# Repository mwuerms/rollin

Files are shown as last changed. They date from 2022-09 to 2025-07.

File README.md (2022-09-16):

# rollin
a self balancing robot, "rolling around"

## Test 1

quick prototyp for using MPU9250 to get acc x, y values and gyro z values (change rate in deg/s !) to calculate present angle:

 +   0° is upright
 + -90° fall over foreward
 +  90° fall over backwards

## Better Serial Plotter

A very nice serial plotter tool (win, mac, linux), using space ' ' or tabs '\t' as value separator.

https://github.com/nathandunk/BetterSerialPlotter#example-arduino-code

Thank you nathandunk (https://github.com/nathandunk)

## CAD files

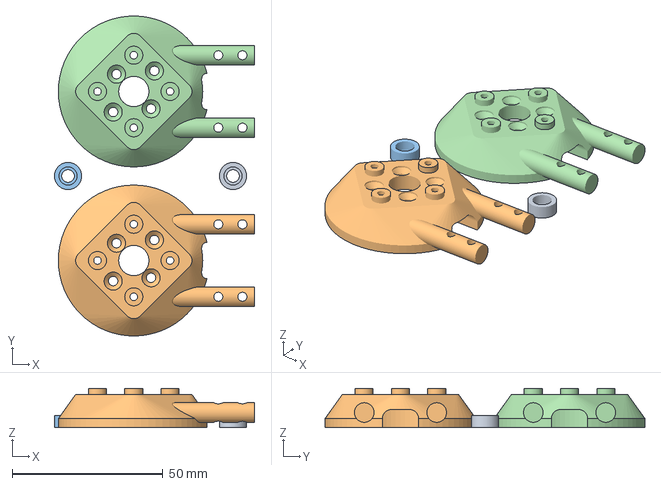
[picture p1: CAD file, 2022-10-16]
openscad/r02/r02_magnet_holder_v1.0.3mf
66.3 x 106.0 x 13.0 mm
r02_magnet_holder_v1.0.stl x 2
r02_motor_holder_v1.0.stl x 2

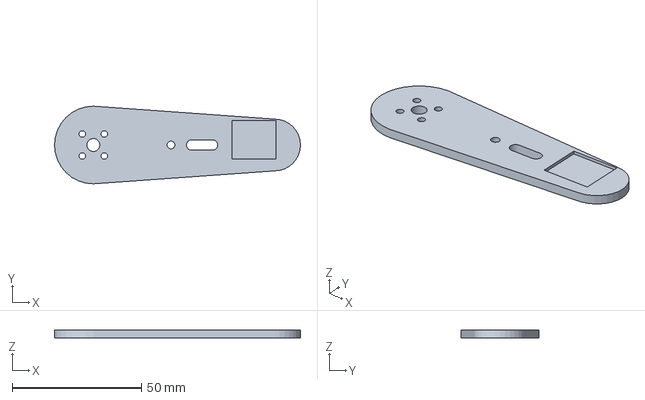
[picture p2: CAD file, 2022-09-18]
openscad/teststand/motor_holderv1.0.3mf
95.0 x 30.0 x 3.00 mm

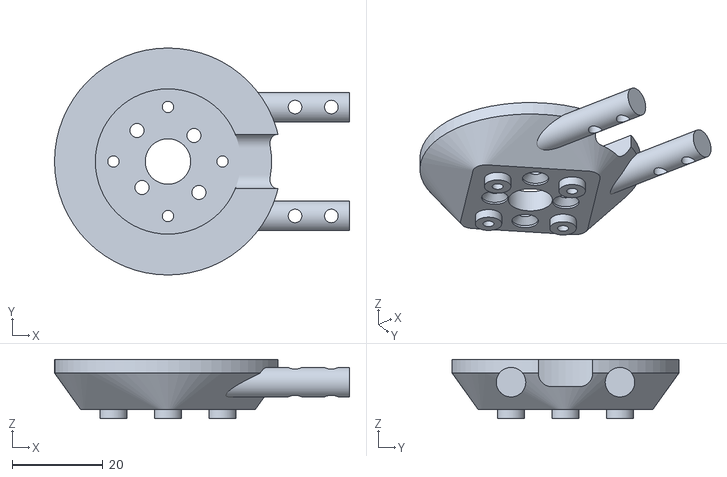
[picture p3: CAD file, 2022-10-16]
openscad/r02/r02_motor_holder_v1.0.stl
65.0 x 50.0 x 13.0

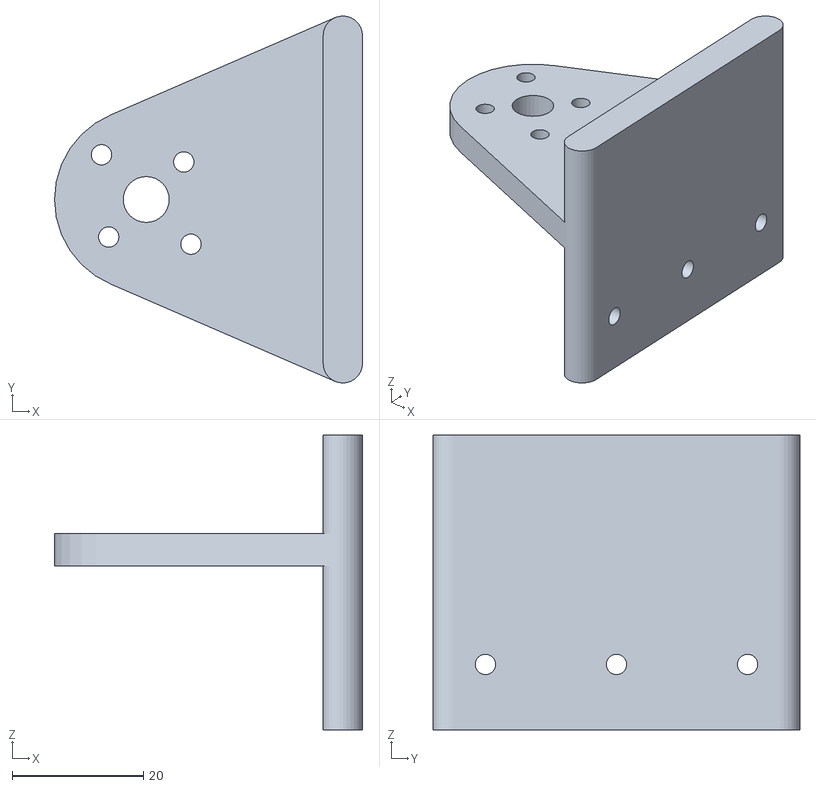
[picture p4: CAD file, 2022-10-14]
openscad/r02/r02_test_stand_v1.0.stl
47.0 x 56.0 x 45.0

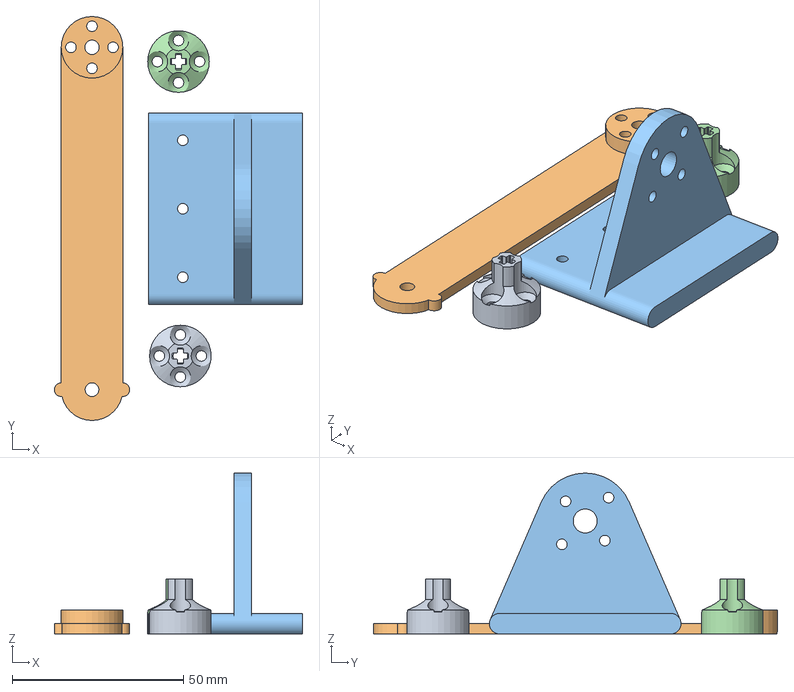
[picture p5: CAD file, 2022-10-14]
openscad/r02/r02_lego_wheel_holder_v1.1.3mf
72.5 x 118.0 x 47.0 mm
r02_lego_wheel_holder_v1.1.stl x 2
r02_test_arm_v1.0.stl
r02_test_stand_v1.0.stl

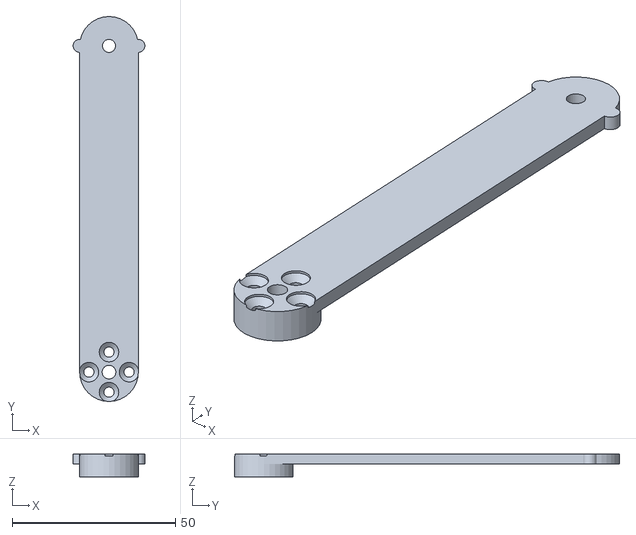
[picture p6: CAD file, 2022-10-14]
openscad/r02/r02_test_arm_v1.0.stl
22.0 x 118.0 x 7.00

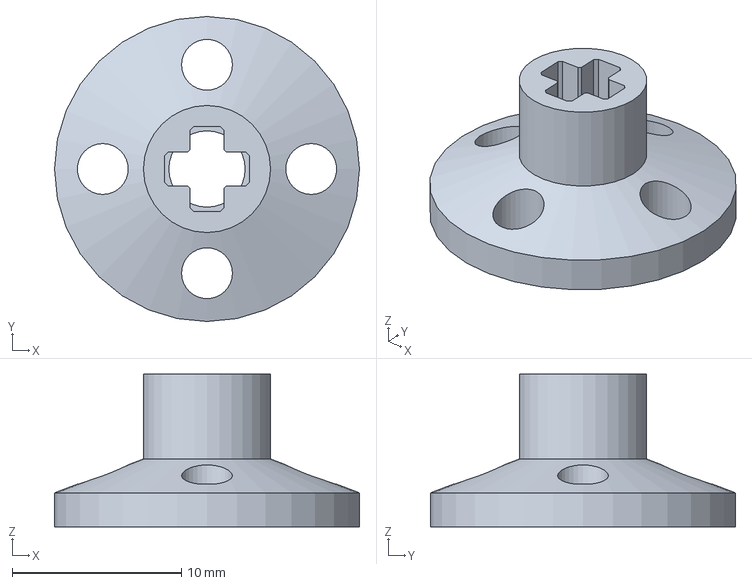
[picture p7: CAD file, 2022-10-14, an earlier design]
openscad/r02/r02_lego_wheel_holder_v1.0.3mf
18.0 x 18.0 x 9.00 mm

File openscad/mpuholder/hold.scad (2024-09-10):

/**
 * Martin Egli
 * 2022-09-07
 * holder for MPU-9250 + Bluepill
 * to get some angle measurements
 */


module pcbMPU9250(loc_res = 32) {
    color("Blue") {
        difference() {
            translate([0, 0, 0])
            cube([26, 16, 1.5]);
            translate([3, 16-3, -1])
            cylinder(d = 3, h = 4.5, $fn = loc_res);
            translate([26-3, 16-3, -1])
            cylinder(d = 3, h = 4.5, $fn = loc_res);
        }
    }
    color("Black") {
        translate([26/2-2, 16/2-2, 1])
        cube([4, 4, 2]);
    }
}

module pcbMPU9250cut(loc_res = 32) {
    hull() {
        translate([3/2, 3/2, -3])
        cylinder(d = 3, h = 5, $fn = loc_res);
        translate([26-3/2, 3/2, -3])
        cylinder(d = 3, h = 5, $fn = loc_res);
    }
}

module pcbMPU9250mounts(loc_res = 32) {
    translate([3, 16-3, 0])
    cylinder(d = 2, h = 2, $fn = loc_res);
    translate([26-3, 16-3, 0])
    cylinder(d = 2, h = 2, $fn = loc_res);
}

module pcbBluePill(loc_res = 32) {
    color("Blue") {
        translate([0, 0, 0])
        cube([53, 22.5, 1.5]);
    }
    color("Black") {
        translate([21, 11, 1])
        rotate([0, 0, -45])
        cube([8, 8, 2]);
    }
    color("Silver") {
        translate([0, 7, 1.5])
        cube([6, 8, 2]);
        
        for(n = [0:1:20-1]) {
            translate([2.3+n*2.54, 3.3, -5])
            cylinder(d = 0.6, h = 8, $fn = loc_res);
            translate([2.3+n*2.54, 3.3+6*2.54, -5])
            cylinder(d = 0.6, h = 8, $fn = loc_res);
        }
    }
}

module pcbBluePill_header_holes(loc_res = 32) {
    for(n = [0:1:20-1]) {
        translate([2.3+n*2.54, 3.3, -5])
        cylinder(d = 1, h = 8, $fn = loc_res);
        translate([2.3+n*2.54, 3.3+6*2.54, -5])
        cylinder(d = 1, h = 8, $fn = loc_res);
    }
}
//cylinder(d = 75.5, h = 10, $fn = 256);

module place_pcbs() {
    translate([(53-26)/2, 25, 0])
    pcbMPU9250();
    pcbBluePill();
}

module pcbHolder(loc_res = 32, show_pcbs = 1) {
    difference() {
        union() {
            // needle
            hull() {
                translate([0, 0, -2])
                cylinder(d = 10, h = 2, $fn = loc_res);
                translate([0, +25, -2])
                cylinder(d = 0.1, h = 2, $fn = loc_res);
            }
            hull() {
                translate([0, 0, -2])
                cylinder(d = 10, h = 2, $fn = loc_res);
                translate([-15, -8, -2])
                cylinder(d = 2, h = 2, $fn = loc_res);
                translate([+15, -8, -2])
                cylinder(d = 2, h = 2, $fn = loc_res);
                translate([-28, -41, -2])
                cylinder(d = 2, h = 2, $fn = loc_res);
                translate([+28, -41, -2])
                cylinder(d = 2, h = 2, $fn = loc_res);
            }
            translate([-29, -43, -2])
            cube([29*2, 2, 28]);
            
            translate([-26/2, -25, 0])
            pcbMPU9250mounts();
        }
        // cut outs
        // center hole
        translate([0, 0, -10])
        cylinder(d = 3, h = 20, $fn = loc_res);
        
        translate([-26/2, -25, 0])
        pcbMPU9250cut();
        
        translate([-53/2, -40, 0])
        rotate([-90, 0, 0])
        translate([0, -26, 0])
        pcbBluePill_header_holes();
    }
    if(show_pcbs) {
        translate([-26/2, -25, 0])
        pcbMPU9250();
        translate([-53/2, -40, 0])
        rotate([-90, 0, 0])
        translate([0, -26, 0])
        pcbBluePill();
    }
}

module stand(loc_res = 32) {
    r1 = 30/2;
    r2 = 55/2;
    nb_marks = 16;
    difference() {
        union() {
            translate([0, 0, 0])
            cylinder(d = 60, h = 1, $fn = loc_res);
            hull() {
                translate([0, 0, 0])
                cylinder(d = 8, h = 1, $fn = loc_res);
                translate([-20, -70, 0])
                cylinder(d = 8, h = 1, $fn = loc_res);
                translate([+20, -70, 0])
                cylinder(d = 8, h = 1, $fn = loc_res);
            }            
            translate([0, 0, -2])
            hull() {
                translate([0, 0, 0])
                cylinder(d = 5, h = 3, $fn = loc_res);
                translate([-20, -70, 0])
                cylinder(d = 5, h = 3, $fn = loc_res);
            }
            translate([0, 0, -2])
            hull() {
                translate([0, 0, 0])
                cylinder(d = 5, h = 3, $fn = loc_res);
                translate([+20, -70, 0])
                cylinder(d = 5, h = 3, $fn = loc_res);
            }
        }
        // center hole
        #translate([0, 0, -10])
        cylinder(d = 3, h = 20, $fn = loc_res);
        
        // scale
        translate([0, 0, 0.5]) // center
        for(n = [0:1:(nb_marks-1)])
        hull() {
            translate([r1*cos(n*360/nb_marks), r1*sin(n*360/nb_marks), 0])
            cylinder(d = 1, h = 2, $fn = loc_res);
            translate([r2*cos(n*360/nb_marks), r2*sin(n*360/nb_marks), 0])
            cylinder(d = 1, h = 2, $fn = loc_res);
        }
        // m3 holes
        translate([-20, -70, -5])
        cylinder(d = 3.2, h = 10, $fn = loc_res);
        translate([+20, -70, -5])
        cylinder(d = 3.2, h = 10, $fn = loc_res);
    }
}

module motorAdapter1(loc_res = 32) {
    difference() {
        union() {
            hull() {
                translate([0, 0, 0])
                cylinder(d = 10, h = 3, $fn = loc_res);
                translate([0, 20, 0])
                cylinder(d = 20, h = 3, $fn = loc_res);
            }
            translate([0, 10, -16])
            cylinder(d = 10, h = 17, $fn = loc_res);
            
            translate([3, 7.5, -16])
            cube([8, 5, 15]);
        }
        // M3 holes
        translate([0, 0, -1])
        cylinder(d = 3, h = 5, $fn = loc_res);
        translate([5, 20, -1])
        cylinder(d = 3, h = 5, $fn = loc_res);
        translate([-5, 20, -1])
        cylinder(d = 3, h = 5, $fn = loc_res);

        // 5mm axle
        translate([0, 10, -17])
        cylinder(d = 5, h = 19, $fn = loc_res);
        translate([8, 5, -8])
        rotate([-90, 0, 0])
        cylinder(d = 3, h = 10, $fn = loc_res);
        translate([2, 9.5, -17])
        cube([10, 1, 17]);
    }
}

module motorAdapter2(loc_res = 32) {
    difference() {
        hull() {
            translate([0, 0, 0])
            cylinder(d = 10, h = 3, $fn = loc_res);
            translate([0, 20, 0])
            cylinder(d = 20, h = 3, $fn = loc_res);
        }
        // needle
        hull() {
            translate([0, 0, -1])
            cylinder(d = 10.5, h = 2, $fn = loc_res);
            translate([0, +25.5, -1])
            cylinder(d = 0.1, h = 2, $fn = loc_res);
        }
        // M3 holes
        translate([0, 0, -1])
        cylinder(d = 3, h = 5, $fn = loc_res);
        translate([5, 20, -1])
        cylinder(d = 3, h = 5, $fn = loc_res);
        translate([-5, 20, -1])
        cylinder(d = 3, h = 5, $fn = loc_res);
    }
}

module stand_base_holder(loc_res = 32) {
    difference() {
        union() {
            hull() {
                translate([0, 0, 0])
                cylinder(d = 8, h = 4, $fn = loc_res);
                translate([+6, -5, 0])
                cylinder(d = 2, h = 4, $fn = loc_res);
                translate([-6, -5, 0])
                cylinder(d = 2, h = 4, $fn = loc_res);
            }
            hull() {
                translate([+6, -5, -1])
                cylinder(d = 2, h = 30, $fn = loc_res);
                translate([-6, -5, -1])
                cylinder(d = 2, h = 30, $fn = loc_res);
            }
        }
        // M3 holes
        translate([0, 0, -1])
        cylinder(d = 3.2, h = 13, $fn = loc_res);
    }
}


// middle axis in the center
/*translate([0, 0, -10])
cylinder(d = 3, h = 20, $fn = 32);
*/

*translate([0, 0, 0]) pcbHolder(32, 0);

*translate([0, 0, -6]) stand(64);
//translate([+20, -70, -5])
stand_base_holder(64);


//translate([0, 0, -8]) motorAdapter1();

//translate([0, 0, 4]) motorAdapter2();

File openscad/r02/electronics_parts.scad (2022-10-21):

/**
 * Martin Egli
 * 2022-09-14
 * electronics
 */

use <parts.scad>

module pcbMPU9250(loc_res = 32) {
    origin();
    color("Blue") {
        difference() {
            translate([0, 0, 0])
            cube([26, 16, 1.5]);
            translate([3, 16-3, -1])
            cylinder(d = 3, h = 4.5, $fn = loc_res);
            translate([26-3, 16-3, -1])
            cylinder(d = 3, h = 4.5, $fn = loc_res);
        }
    }
    color("Black") {
        translate([26/2-2, 16/2-2, 1])
        cube([4, 4, 2]);
    }
}

module pcbMPU9250cut(loc_res = 32) {
    hull() {
        translate([3/2, 3/2, -3])
        cylinder(d = 3, h = 5, $fn = loc_res);
        translate([26-3/2, 3/2, -3])
        cylinder(d = 3, h = 5, $fn = loc_res);
    }
}

module pcbMPU9250mounts(loc_res = 32) {
    translate([3, 16-3, 0])
    cylinder(d = 2, h = 2, $fn = loc_res);
    translate([26-3, 16-3, 0])
    cylinder(d = 2, h = 2, $fn = loc_res);
}

module mpu650pcb(loc_res = 32) {
    origin();
    color("Blue")
    translate([0, 0, 0])
    cube([16, 14, 1]);
    color("White")
    translate([3.5, -2, 1])
    cube([10, 5.5, 4]);
    color("Gray")
    translate([7, 7, 1])
    cube([4, 4, 1]);
}

module gimbal_arduino_v3_0_pcb(loc_res = 32) {
    origin();
    // PCB
    difference() {
        union() {
            color("Blue")
            translate([0, 0, 0])
            cube([51, 52, 1.6]);

            color("Silver")
            translate([2.4, 4, -0.05])
            cylinder(d=4, h = 1.7, $fn = loc_res);
            color("Silver")
            translate([51-3.4, 4, -0.05])
            cylinder(d=4, h = 1.7, $fn = loc_res);
            color("Silver")
            translate([2.4, 52-3, -0.05])
            cylinder(d=4, h = 1.7, $fn = loc_res);
            color("Silver")
            translate([51-3.4, 52-3, -0.05])
            cylinder(d=4, h = 1.7, $fn = loc_res);
        }
        translate([2.4, 4, -0.1])
        cylinder(d=3.4, h = 1.8, $fn = loc_res);
        translate([51-3.4, 4, -0.1])
        cylinder(d=3.4, h = 1.8, $fn = loc_res);
        translate([2.4, 52-3, -0.1])
        cylinder(d=3.4, h = 1.8, $fn = loc_res);
        translate([51-3.4, 52-3, -0.1])
        cylinder(d=3.4, h = 1.8, $fn = loc_res);
    }
    // mini USB
    color("Silver")
    translate([35, -2, 1.5])
    cube([7.5, 9, 4]);
    // i2c - mpu650
    color("White")
    translate([3.5, -2, 1])
    cube([10, 5.5, 4]);
    // MCU
    color("Gray")
    translate([14, 13, 1.6])
    cube([7, 7, 1]);

    // 6xMOSFET
    color("Gray")
    for(n=[0:1:5])
    translate([10+n*6, 40, 1.6])
    cube([5, 4, 1]);
}

module pcbBluePill(loc_res = 32) {
    origin();
    color("Blue") {
        translate([0, 0, 0])
        cube([53, 22.5, 1.5]);
    }
    color("Black") {
        translate([21, 11, 1])
        rotate([0, 0, -45])
        cube([8, 8, 2]);
    }
    color("Silver") {
        translate([0, 7, 1.5])
        cube([6, 8, 2]);
        
        for(n = [0:1:20-1]) {
            translate([2.3+n*2.54, 3.3, -5])
            cylinder(d = 0.6, h = 8, $fn = loc_res);
            translate([2.3+n*2.54, 3.3+6*2.54, -5])
            cylinder(d = 0.6, h = 8, $fn = loc_res);
        }
    }
}

module pcbBluePill_header_holes(loc_res = 32) {
    for(n = [0:1:20-1]) {
        translate([2.3+n*2.54, 3.3, -5])
        cylinder(d = 1, h = 8, $fn = loc_res);
        translate([2.3+n*2.54, 3.3+6*2.54, -5])
        cylinder(d = 1, h = 8, $fn = loc_res);
    }
}

module pcbAS5600_mount_holes_cut(cut_dia = 3.5, cut_len = 10, loc_res = 32) {
    a = (19.7+12.4)/2/2;
    translate([+a,+a, 0])
    cylinder(d = cut_dia, h = cut_len, $fn = loc_res);
    translate([+a, -a, 0])
    cylinder(d = cut_dia, h = cut_len, $fn = loc_res);
    translate([-a, +a, 0])
    cylinder(d = cut_dia, h = cut_len, $fn = loc_res);
    translate([-a, -a, 0])
    cylinder(d = cut_dia, h = cut_len, $fn = loc_res);
}

module pcbAS5600_pcb(pcb_th = 1.5, loc_res = 32) {
    a = 23/2;
    hull() {
        translate([+a, +a, 0])
        cylinder(r = 3, h = pcb_th, $fn = loc_res);
        translate([+a, -a, 0])
        cylinder(r = 3, h = pcb_th, $fn = loc_res);
        translate([-a, +a, 0])
        cylinder(r = 3, h = pcb_th, $fn = loc_res);
        translate([-a, -a, 0])
        cylinder(r = 3, h = pcb_th, $fn = loc_res);
    }
}

module pcbAS5600(loc_res = 32) {
    difference() {
        union() {
            color("White")
            translate([0, 0, 0])
            pcbAS5600_pcb();
            // SOIC-8 4*5 mm
            color("Gray")
            translate([-2, -2.5, 1.5])
            cube([4, 5, 1]);
        }
        translate([0, 0, -1])
        pcbAS5600_mount_holes_cut();
    }
}

//pcbMPU9250();
//pcbBluePill();

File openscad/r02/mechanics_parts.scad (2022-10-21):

/**
 * Martin Egli
 * 2022-09-14
 * mechanical parts
 */

use <parts.scad>
use <screws.scad>

module lego_axis_cut(len = 10) {
    hull() {
        translate([-1.0, -0.9, 0]) 
        cube([2.0, 1.8, len]);
        translate([-0.9, -1.0, 0]) 
        cube([1.8, 2.0, len]);
    }
    hull() {
        translate([-2.4, -0.7, 0]) 
        cube([4.8, 1.4, len]);
        translate([-2.2, -0.9, 0]) 
        cube([4.4, 1.8, len]);
    }
    hull() {
        translate([-0.9, -2.2, 0]) 
        cube([1.8, 4.4, len]);
        translate([-0.7, -2.4, 0]) 
        cube([1.4, 4.8, len]);
    }
}

module bldc5010_m3cut_rotor(show = 1, len = 10, loc_res = 32) {
    if(show) {
        origin();
    }
    r1 = (15+9.6)/2/2;
    for(n=[0:1:3]) {
        translate([r1*cos(n*90), r1*sin(n*90), 0]) {
            translate([0, 0, -len]) 
            cylinder(d = 3.1, h = len, $fn = loc_res);
            translate([0, 0, 0]) 
            cylinder(d1 = 3.1, d2= 6.0, h = 1.5, $fn = loc_res);
            translate([0, 0, 1.5]) 
            cylinder(d = 6.0, h = len, $fn = loc_res);
        }
    }
}

module bldc5010_m3cut_stator(show = 1, len = 10, loc_res = 32) {
    if(show) {
        origin();
    }
    r1 = (19+13.4)/2/2;
    for(n=[0:2:3]) {
        translate([r1*cos(n*90), r1*sin(n*90), 0]) {
            translate([0, 0, 0]) 
            cylinder(d = 3.1, h = len, $fn = loc_res);
            translate([0, 0, -1.5]) 
            cylinder(d2 = 3.1, d1= 6.0, h = 1.5, $fn = loc_res);
            translate([0, 0, -(len+1.5)]) 
            cylinder(d = 6.0, h = len, $fn = loc_res);
        }
    }
    r2 = (22+16.6)/2/2;
    for(n=[1:2:3]) {
        translate([r2*cos(n*90), r2*sin(n*90), 0]) {
            translate([0, 0, 0]) 
            cylinder(d = 3.1, h = len, $fn = loc_res);
            translate([0, 0, -1.5]) 
            cylinder(d2 = 3.1, d1= 6.0, h = 1.5, $fn = loc_res);
            translate([0, 0, -(len+1.5)]) 
            cylinder(d = 6.0, h = len, $fn = loc_res);
        }
    }
}

module bldc5010_motor(show = 1, loc_res = 32) {
    if(show) {
        origin(25);
        #translate([0, 0, 20])
        bldc5010_m3cut_rotor();
        #translate([0, 0, -2])
        bldc5010_m3cut_stator();
    }
    color("LightGray") {
        difference() {
            union() {
                // from bottom
                translate([0,0, 0])
                cylinder(d = 25, h = 2, $fn = loc_res);
                translate([0,0, 0])
                cylinder(d = 14.4, h = 19, $fn = loc_res);
                translate([0,0, 7])
                cylinder(d = 50, h = 10, $fn = loc_res);
                translate([0,0, 17])
                cylinder(d1 = 50, d2 = 18, h = 2, $fn = loc_res);
            }
            translate([0, 0, 20]) 
            bldc5010_m3cut_rotor();
            translate([0, 0, -2])
            bldc5010_m3cut_stator();
        }
    }
    color("DarkGray") {
        translate([0,0, -1.5])
        cylinder(d = 4, h = 24, $fn = loc_res);
    }
    translate([0, 0, 3])
    rotate([0, 0, 45]) {
        color("Red")
        translate([4, -2.5, 0])
        rotate([0, 90, 0])
        cylinder(d = 2.5, h=20, $fn = loc_res);
        color("Black")
        translate([4, 0, 0])
        rotate([0, 90, 0])
        cylinder(d = 2.5, h=20, $fn = loc_res);
        color("Yellow")
        translate([4, +2.5, 0])
        rotate([0, 90, 0])
        cylinder(d = 2.5, h=20, $fn = loc_res);
    }
}

module flycat2204_rotor_cut(loc_res = 32) {
    // M2 holes rotor
    for(n=[0:1:3])
        translate([6*cos(n*90+45), 6*sin(n*90+45), 2.5])
        cylinder(d = 2.2, h = 20, $fn = loc_res);
}

module flycat2204_rotor_cut_m2x6mm(loc_res = 32) {
    // M2 holes rotor
    for(n=[0:1:3])
        translate([6*cos(n*90+45), 6*sin(n*90+45), 0])
        m2x6mm_cut();
}

module flycat2204_stator_cut(loc_res = 32) {
    // M2.5 holes stator
    for(n=[0:1:3])
    translate([6*cos(n*90+45), 6*sin(n*90+45), -5])
    cylinder(d = 2.2, h = 3.5+5, $fn = loc_res);
}

module flycat2204(loc_res = 32) {
    origin();
    color("Gray") {
        difference() {
            union() {
                // base
                translate([0, 0, 0])
                cylinder(d = 28, h = 3.4, $fn = loc_res);
                // rotor
                translate([0, 0, 3.5])
                cylinder(d = 28, h = 13-3.5, $fn = loc_res);
            }
            hull() {
                translate([6+2, +(6-2), -0.5])
                cylinder(r = 2, h = 1, $fn = loc_res);
                translate([6+2+6, +(6-2), -0.5])
                cylinder(r = 2, h = 1, $fn = loc_res);
                translate([6+2+6, -(6-2), -0.5])
                cylinder(r = 2, h = 1, $fn = loc_res);
                translate([6+2, -(6-2), -0.5])
                cylinder(r = 2, h = 1, $fn = loc_res);
            }
            translate([0, 0, -1])
            cylinder(d = 3.5, h = 13+2, $fn = loc_res);

            flycat2204_rotor_cut();
            flycat2204_stator_cut();
        }
    }
}

//bldc5010_mockup();
flycat2204();

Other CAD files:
openscad/r02/r02.scad
openscad/r02/r02_lego_wheel_holder_v1.0.stl
openscad/r02/r02_lego_wheel_holder_v1.1.stl
openscad/r02/r02_magnet_holder_v1.0.stl
openscad/r02/screws.scad
openscad/r03/r03.scad
openscad/r04/electronics_parts.scad
openscad/r04/mechanics_parts.scad
openscad/r04/parts.scad
openscad/r04/printparts.scad
openscad/r04/rtest04.scad
openscad/r04/screws.scad
openscad/r1/r_01.scad
openscad/teststand/motor_holderv1.0.stl
openscad/teststand/stand.scad

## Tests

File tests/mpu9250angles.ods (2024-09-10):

Umschlagsmessung |  |  |  |  |  |  |  | Mittelwerte Umschlagsmessung |  |  | 16384
2022-09-09, Martin Egli
 |  |  |  |  |  |  |  |  |  |  |  |  |  |  |  | Messung von angle 0 … 180 … 0° |  |  |  |  |  |  | corr |  | LENGTH
angle | alpha | acc x | acc y | acc z | gyro x | gyro y | gyro z | angle | alpha | acc x | acc y | acc z | gyro x | gyro y | gyro z |  | acc x | acc y | acc z | gyro x | gyro y | gyro z | acc x | acc y |  | acc x/LENGTH | acc y/LENGTH | atan2 | angle in ° | ATAN2(corr)
0 | 90 | -112 | 16480 | 2956 | -150 | -141 | -358 | 0 | 90 | -116.95652173913 | 16533.1304347826 | 2896.86956521739 | -218.369565217391 | -78.2173913043478 | -321.369565217391 |  | 848 | 16508 | 3992 | -402 | -112 | -113 | 837.547161565999 | 16358.8357047817 | 16380.2622342833 | 0.0511314867605136 | 0.998691930007277 | 1.51964253384155 | 87.0691035576872 | 2.93089644231278
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

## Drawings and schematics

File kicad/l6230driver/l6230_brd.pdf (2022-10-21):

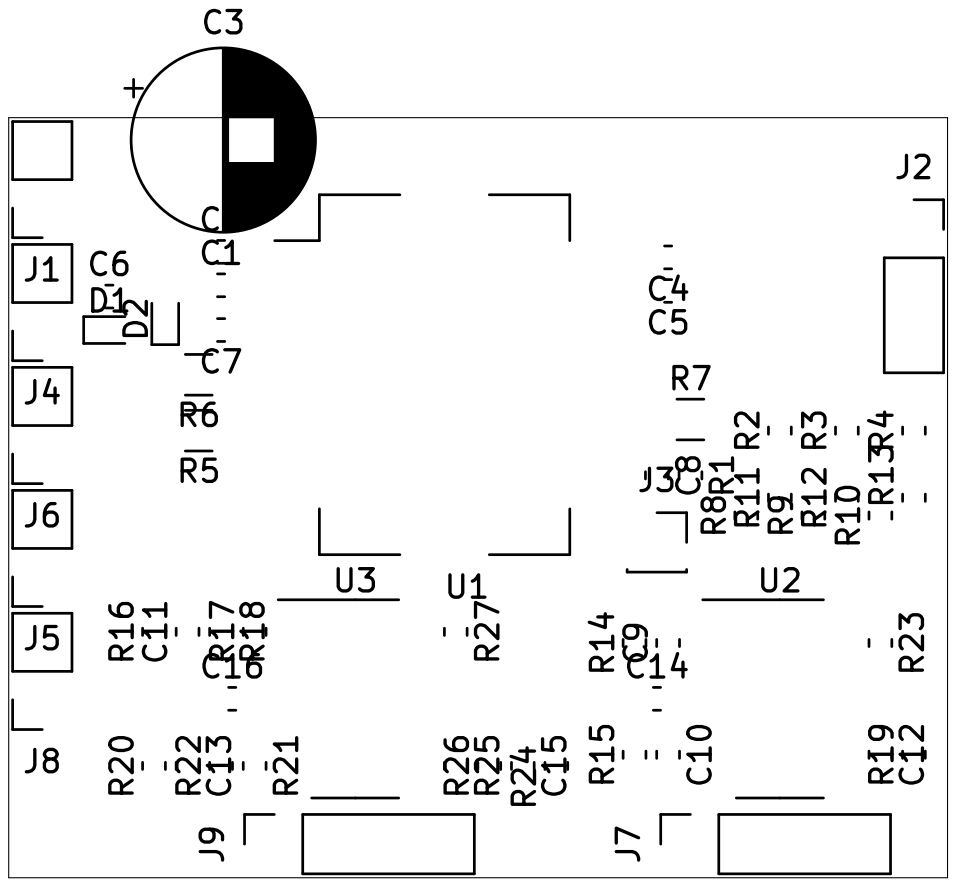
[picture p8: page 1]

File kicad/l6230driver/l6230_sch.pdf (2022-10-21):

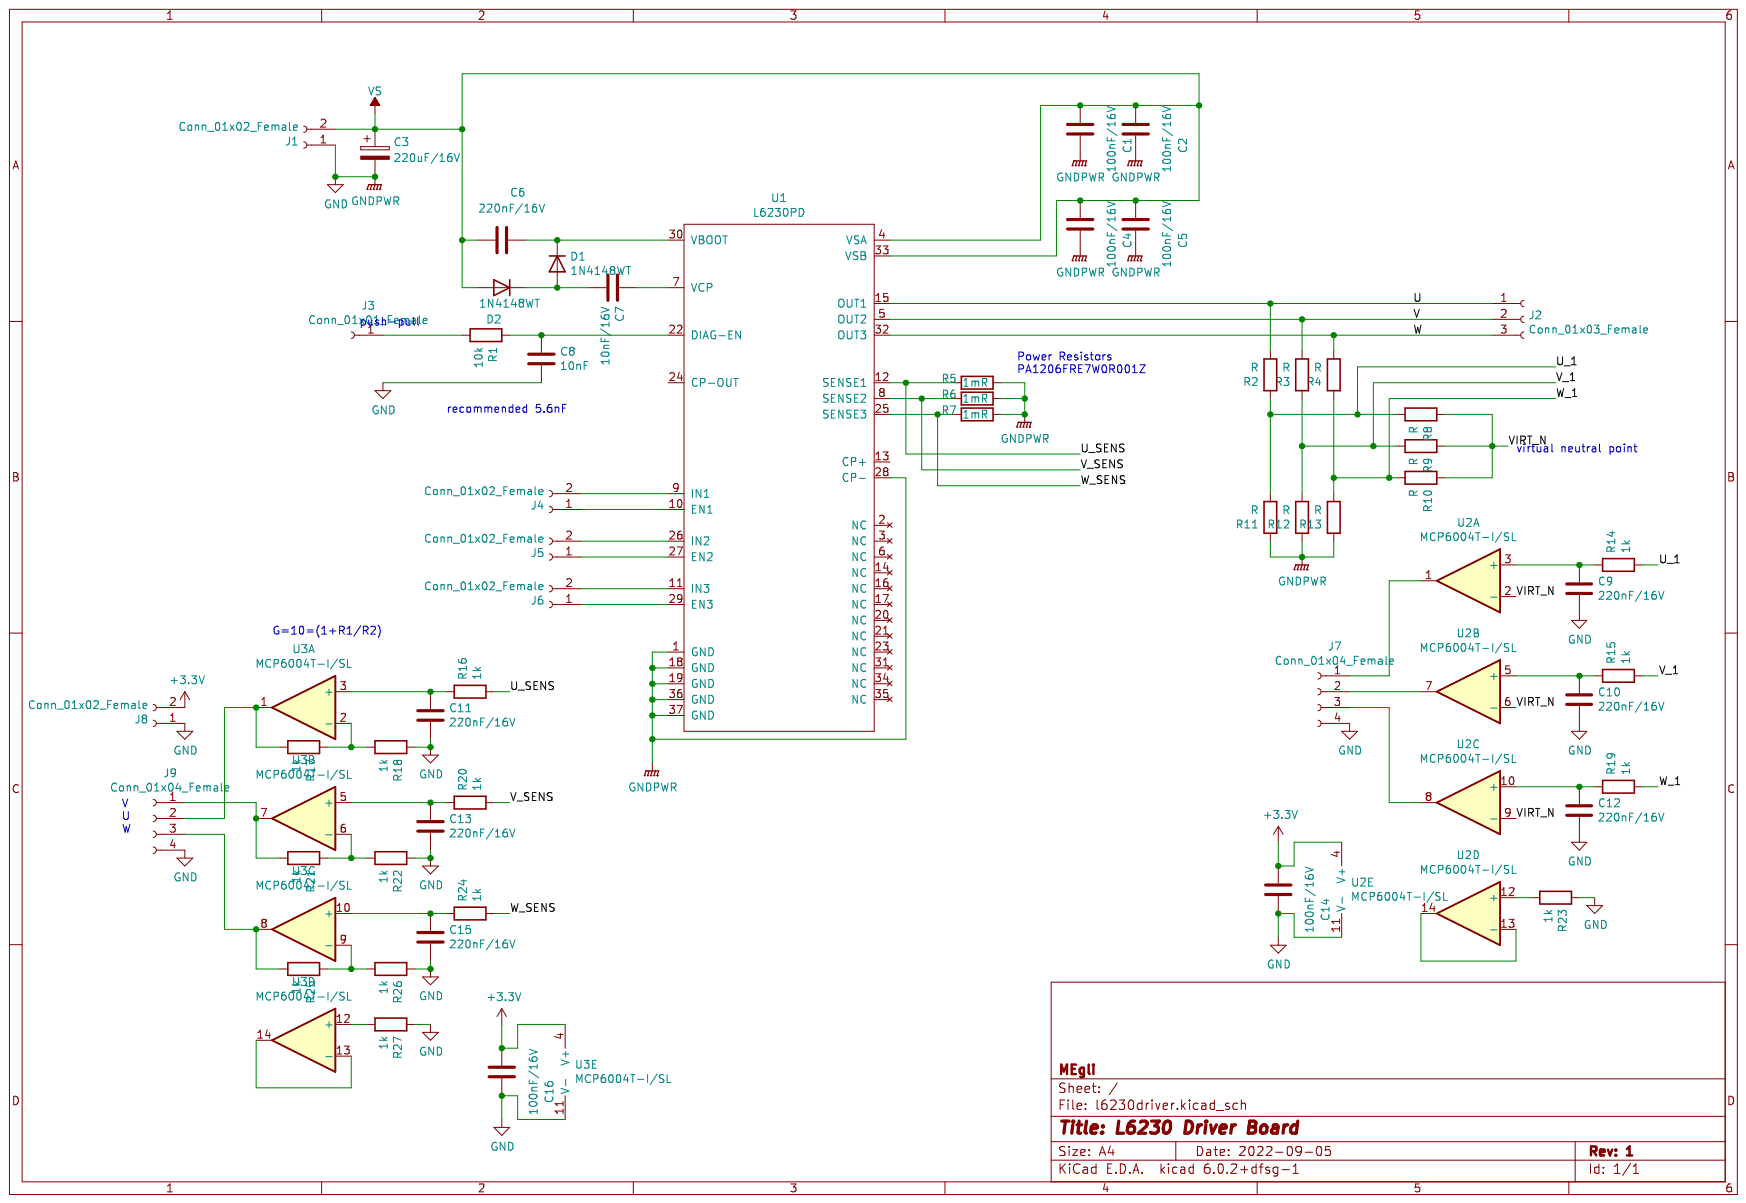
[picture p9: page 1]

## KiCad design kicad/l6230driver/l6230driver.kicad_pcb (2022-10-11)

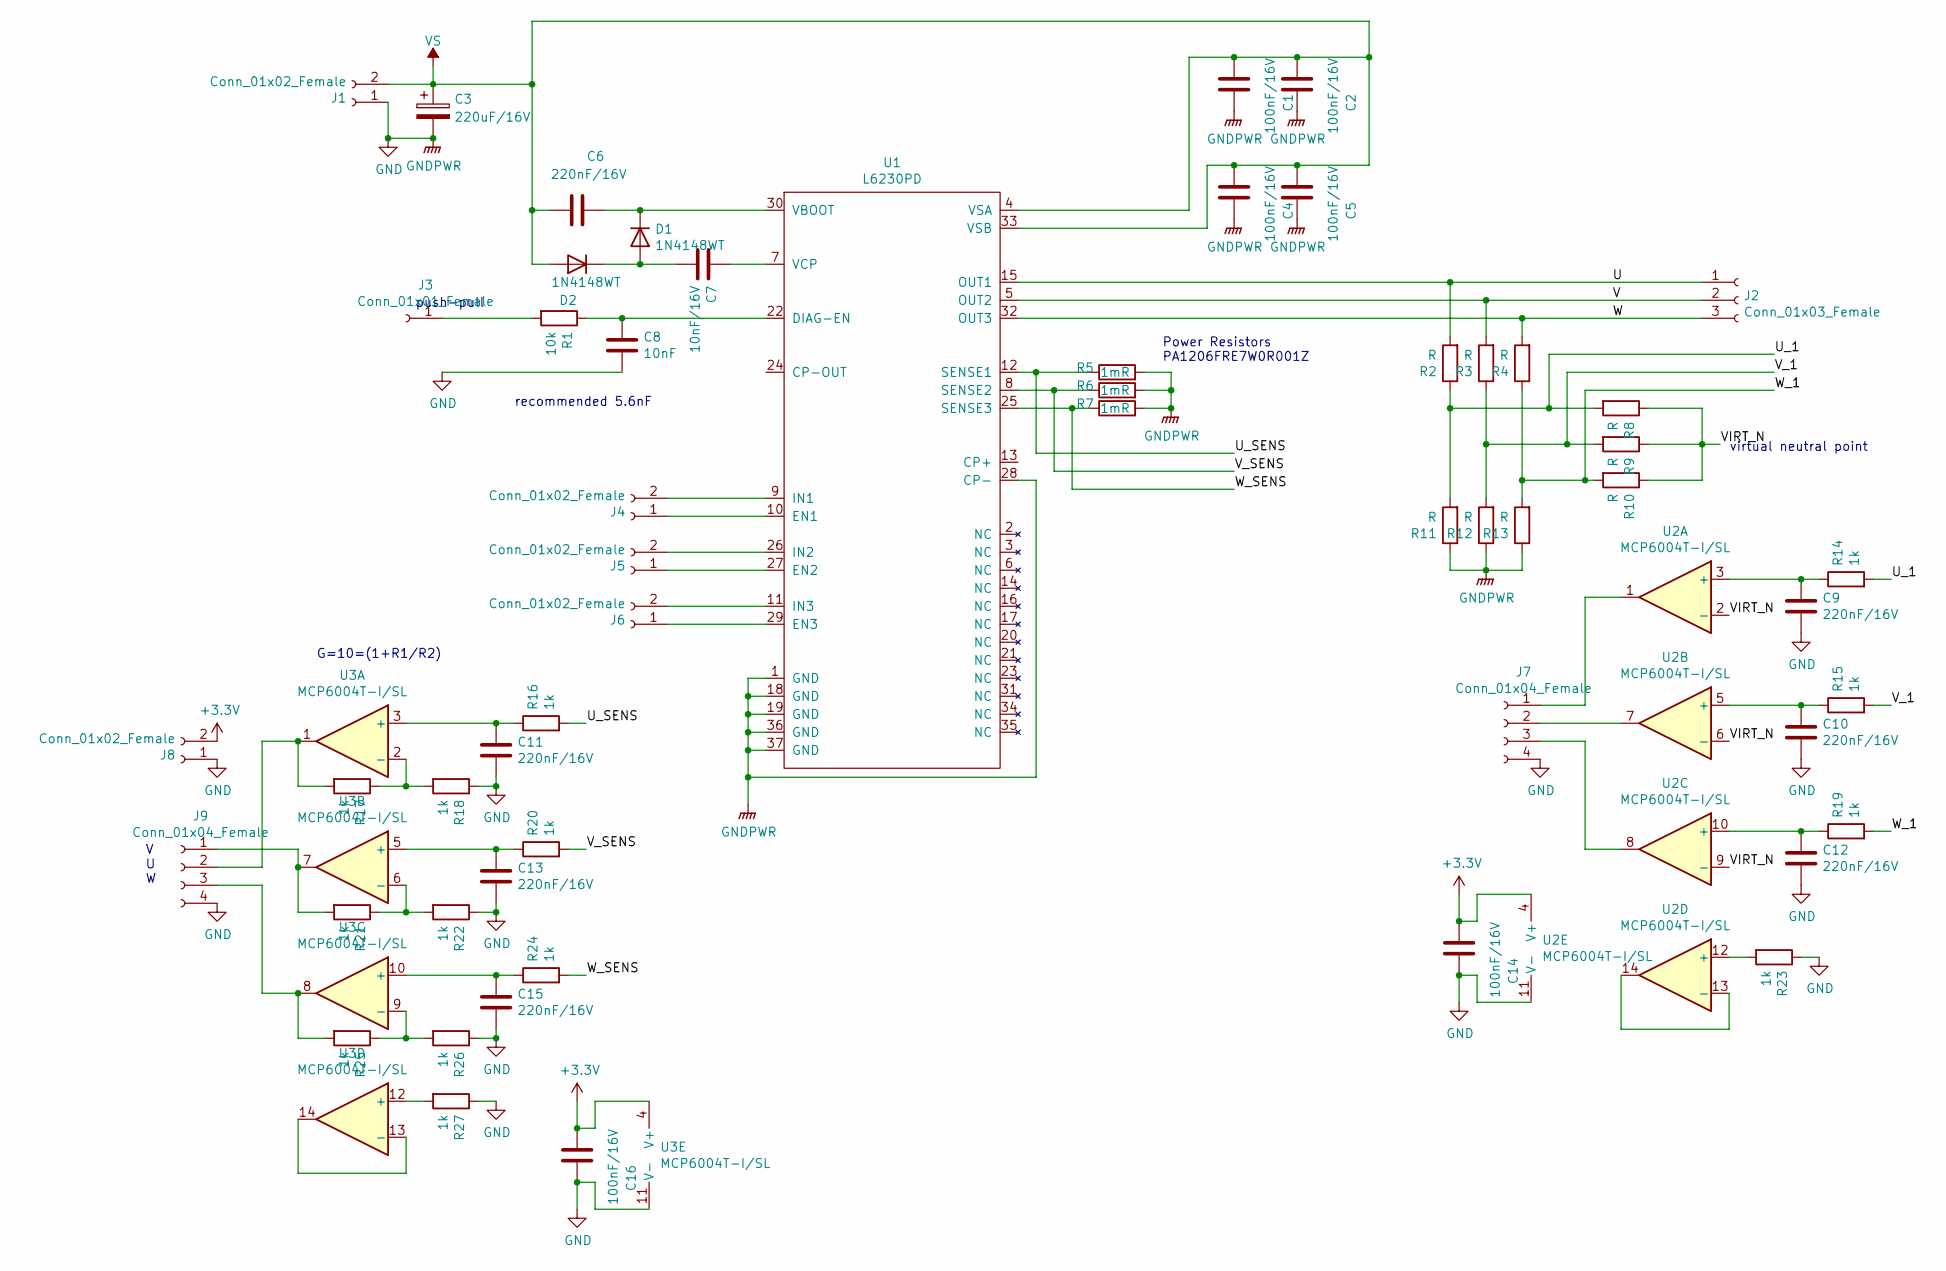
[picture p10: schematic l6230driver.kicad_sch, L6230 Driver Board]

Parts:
C1, C2, C4, C5, C14, C16: 100nF/16V; C_0603_1608Metric
C3: 220uF/16V; CP_Radial_D8.0mm_P2.50mm
C6, C9, C10, C11, C12, C13, C15: 220nF/16V; C_0603_1608Metric
C7: 10nF/16V; C_0603_1608Metric
C8: 10nF; C_0603_1608Metric
D1, D2: 1N4148WT; D_SOD-523
J1, J4, J5, J6, J8: Conn_01x02_Female; PinSocket_1x02_P2.54mm_Vertical
J2: Conn_01x03_Female; PinSocket_1x03_P2.54mm_Vertical
J3: Conn_01x01_Female; PinSocket_1x01_P2.54mm_Vertical
J7, J9: Conn_01x04_Female; PinSocket_1x04_P2.54mm_Vertical
R1: 10k; R_0603_1608Metric
R2, R3, R4, R8, R9, R10, R11, R12, R13: R; R_0603_1608Metric
R5, R6, R7: 1mR; R_1206_3216Metric
R14, R15, R16, R17, R18, R19, R20, R21, R22, R23, R24, R25, R26, R27: 1k; R_0603_1608Metric
U1: L6230PD; HSOP-36
U2, U3: MCP6004T-I/SL; SOIC-14_3.9x8.7mm_P1.27mm

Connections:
+3V3: C14.2, C16.2, J8.2, U2.4 (V+), U3.4 (V+)
/U: J2.1, R2.2, U1.15 (OUT1)
/U_1: R2.1, R8.2, R11.2, R14.2
/U_SENS: R5.1, R16.2, U1.12 (SENSE1)
/V: J2.2, R3.2, U1.5 (OUT2)
/VIRT_N: R8.1, R9.1, R10.1, U2.2 (-), U2.6 (-), U2.9 (-)
/V_1: R3.1, R9.2, R12.2, R15.2
/V_SENS: R6.1, R20.2, U1.8 (SENSE2)
/W: J2.3, R4.2, U1.32 (OUT3)
/W_1: R4.1, R10.2, R13.2, R19.2
/W_SENS: R7.1, R24.2, U1.25 (SENSE3)
GND: C1.1, C2.1, C3.2, C4.1, C5.1, C8.2, C9.2, C10.2, C11.2, C12.2, C13.2, C14.1, C15.2, C16.1, J1.1, J7.4, J8.1, J9.4, R5.2, R6.2, R7.2, R11.1, R12.1, R13.1, R18.1, R22.1, R23.1, R26.1, R27.1, U1.1 (GND), U1.18 (GND), U1.19 (GND), U1.28 (CP-), U1.36 (GND), U1.37 (GND), U2.11 (V-), U3.11 (V-)
unnamed: C6.1, D1.1 (K), U1.30 (VBOOT)
unnamed: C7.1, U1.7 (VCP)
unnamed: C7.2, D1.2 (A), D2.1 (K)
unnamed: C8.1, R1.1, U1.22 (DIAG-EN)
unnamed: C9.1, R14.1, U2.3 (+)
unnamed: C10.1, R15.1, U2.5 (+)
unnamed: C11.1, R16.1, U3.3 (+)
unnamed: C12.1, R19.1, U2.10 (+)
unnamed: C13.1, R20.1, U3.5 (+)
unnamed: C15.1, R24.1, U3.10 (+)
unnamed: J3.1, R1.2
unnamed: J4.1, U1.10 (EN1)
unnamed: J4.2, U1.9 (IN1)
unnamed: J5.1, U1.27 (EN2)
unnamed: J5.2, U1.26 (IN2)
unnamed: J6.1, U1.29 (EN3)
unnamed: J6.2, U1.11 (IN3)
unnamed: J7.1, U2.1
unnamed: J7.2, U2.7
unnamed: J7.3, U2.8
unnamed: J9.3, R25.2, U3.8
unnamed: R17.1, R18.2, U3.2 (-)
unnamed: J9.2, R17.2, U3.1
unnamed: R21.1, R22.2, U3.6 (-)
unnamed: J9.1, R21.2, U3.7
unnamed: R23.2, U2.12 (+)
unnamed: R25.1, R26.2, U3.9 (-)
unnamed: R27.2, U3.12 (+)
unnamed: U2.13 (-), U2.14
unnamed: U3.13 (-), U3.14
VS: C1.2, C2.2, C3.1, C4.2, C5.2, C6.2, D2.2 (A), J1.2, U1.4 (VSA), U1.33 (VSB)

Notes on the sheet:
V U W
push-pull
recommended 5.6nF
virtual neutral point
Power Resistors PA1206FRE7W0R001Z
G=10=(1+R1/R2)

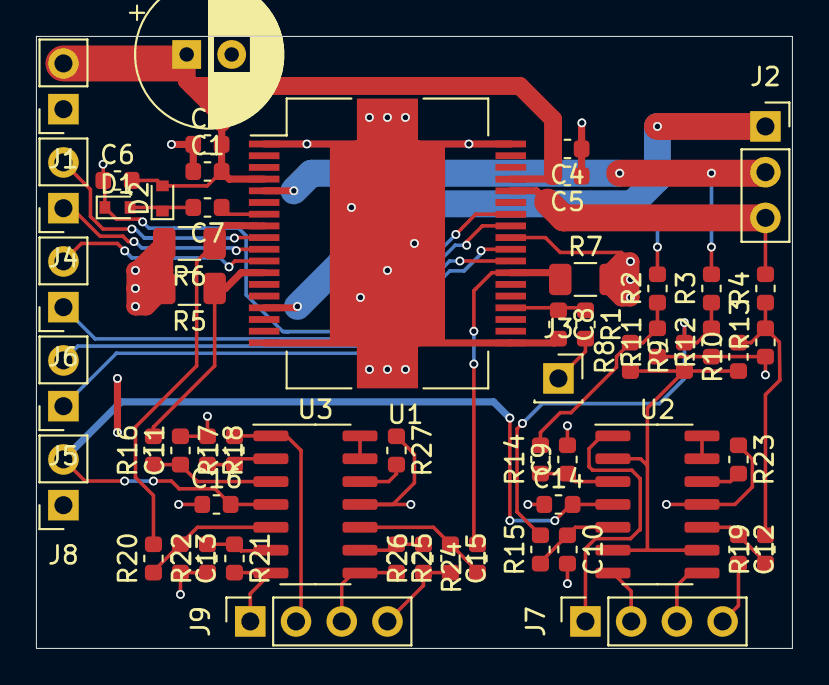
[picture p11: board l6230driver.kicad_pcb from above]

Board: 2 copper layers, 42.0 x 34.0 mm, 57 parts (0 on the bottom side), 43 nets.

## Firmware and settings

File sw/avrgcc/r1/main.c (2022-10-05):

/**
 * Martin Egli
 * 2022-06-06
 *
 * project on github: https://github.com/mwuerms/pwmgen
 * avr-gcc see: /usr/lib/avr
 * http://www.nongnu.org/avr-libc/user-manual/using_tools.html
 */

/* - includes --------------------------------------------------------------- */
#include <stdint.h>
#include <avr/interrupt.h>
#include <string.h>
#include <math.h>

#include "project.h"
#include "macrolib.h"
#include "mcusleep.h"
#include "motor.h"
#include "wdt.h"
#include "mpu6500.h"
#include "uart.h"
#include "string_buffer.h"
#include "pid.h"
#include "nunchuck.h"

/* - defines ---------------------------------------------------------------- */

/* - public variables ------------------------------------------------------- */
volatile uint8_t global_events;
volatile uint8_t global_display_events;
volatile uint8_t global_button_events;

float pid_return_value;

#define DBG_PIN0_OUT() (DDRB |= _BV(4))
#define DBG_PIN0_SET() (PORTB |= _BV(4))
#define DBG_PIN0_CLR() (PORTB &= ~_BV(4))

uint8_t sens_buffer[16];
int16_t acc_x, acc_y, gyr_z;

float angle_acc, angle_gyr, angle_deg, angle_deg_prev, angle_error_deg;

int16_t angle_index, motor_index_error, motor_index = 0;
#define MOTOR_INDEX_MAX ((7 * 48) - 1)
#define MOTOR_INDEX_MIN -(7 * 48)

#define RAD_TO_DEG (180.0f / M_PI)

int8_t speed;

/**
 * main loop
 */
int main(void)
{
    uint8_t local_events = 0;
    // init
    sleep_mode_init();
    use_sleep_mode(ACTIVE);

    uart_Init(UBRR_VAL_57600);
    uart_puts("rollin am start\n");

    // pid_init(2.5f, 0.0f, 0.0f); // not bad
    pid_init(1.45f, 0.0f, 0.0035f);

    mpu6500_init();
    mpu6500_set_config();

    nunchuck_start_unencrypred();
    motor_start();
    motor_set_speed(1);
    // motor_send_event_after_nb_ticks(625, EV_READ_SENSOR); // 10 ms
    // motor_send_event_after_nb_ticks(468, EV_READ_SENSOR); // 7.5 ms
    //  motor_send_event_after_nb_ticks(62500 / 2, EV_UPDATE_PWM); // 500 ms

    DBG_PIN0_OUT();
    DBG_PIN0_CLR();

    angle_deg_prev = 0.0f;
    motor_index = 0;
    speed = 0;

    sei();

    // event loop
    while (1)
    {
        if (local_events & EV_UPDATE_PWM)
        {
            motor_send_event_after_nb_ticks(62500 / 2, EV_UPDATE_PWM); // 500 ms
            // found 7 pole pairs
            DBG_PIN0_SET();
            wdtTimer_StartTimeout(60, WDT_TIMER_INTERVAL_1S, EV_UPDATE_PWM);

            motor_set_speed(speed);
            string_buffer_new();
            string_buffer_append_int8(speed);
            string_buffer_append_new_line();
            string_buffer_send_uart();

            speed++;
            if (speed > 20)
                speed = -20;

            DBG_PIN0_CLR();
        }

        if (local_events & EV_READ_SENSOR)
        {
            // wdtTimer_StartTimeout(2, WDT_TIMER_INTERVAL_16MS, EV_READ_SENSOR);
            // motor_send_event_after_nb_ticks(625, EV_READ_SENSOR); // 10 ms
            motor_send_event_after_nb_ticks(468, EV_READ_SENSOR); // 7.5 ms

            // get sensor values
            mpu6500_read_sensor_data(sens_buffer, 14);
            acc_x = (int16_t)(sens_buffer[0] << 8) + sens_buffer[1];
            acc_y = (int16_t)(sens_buffer[2] << 8) + sens_buffer[3];
            gyr_z = (int16_t)(sens_buffer[12] << 8) + sens_buffer[13];

            // calc angles
            angle_acc = (float)atan2((double)acc_x, (double)acc_y);
            angle_acc *= RAD_TO_DEG;
            // angle_gyr = (((float)gyr_z) / 250.0f) * 0.010f; // 0.0477455f; // gyr_z_rate_dps * sample_rate_ps
            angle_gyr = (((float)gyr_z) / 250.0f) * 0.0075f; // gyr_z_rate_dps * sample_rate_ps
            angle_deg = 0.95f * (angle_deg_prev + angle_gyr) + 0.05f * angle_acc;
            angle_deg_prev = angle_deg;

            angle_error_deg = 0.0f - angle_deg;
            // pid_return_value = pid_exec(angle_error_deg, 0.01f);
            pid_return_value = pid_exec(angle_error_deg, 1); // 0.0075f);

            speed = (int8_t)pid_return_value;

            string_buffer_new();
            string_buffer_append_float(angle_deg, 3);
            /*string_buffer_append_separator();
            string_buffer_append_float(angle_error_deg, 3);
            string_buffer_append_separator();
            string_buffer_append_float(pid_return_value, 3);*/
            string_buffer_append_separator();
            string_buffer_append_int8(speed);
            string_buffer_append_new_line();
            string_buffer_send_uart();

            // angle_index = ((int16_t)angle_deg) * 8;
            /*if (speed > 5)
                speed = 5;
            if (speed < -5)
                speed = -5;*/
            motor_set_speed(speed);

            nunchuck_read_raw(sens_buffer, 6);
        }

        while (1)
        {
            cli();
            // check if there is a new event
            local_events = global_events;

            global_events = 0;
            if (local_events)
            {
                sei();
                break;
            }
            // wait here for new event
            enter_sleep_mode();
        }
    }
    return (0);
}

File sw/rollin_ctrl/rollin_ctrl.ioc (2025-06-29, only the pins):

Mcu.UserName=STM32F103C8Tx
PA0-WKUP.Signal=S_TIM2_CH1_ETR
PA1.Signal=S_TIM2_CH2
PA10.Signal=S_TIM1_CH3
PA13.Signal=SYS_JTMS-SWDIO
PA14.Signal=SYS_JTCK-SWCLK
PA15.Signal=GPIO_Output
PA2.Signal=S_TIM2_CH3
PA3.Signal=GPXTI3
PA4.GPIO_Label=SPI1_NSS
PA4.Signal=GPIO_Output
PA5.Signal=SPI1_SCK
PA6.Signal=SPI1_MISO
PA7.Signal=SPI1_MOSI
PA8.Signal=S_TIM1_CH1
PA9.Signal=S_TIM1_CH2
PB0.Signal=ADCx_IN8
PB1.Signal=ADCx_IN9
PB12.Signal=GPIO_Output
PB13.Signal=GPIO_Output
PB14.Signal=GPIO_Output
PB6.Signal=USART1_TX
PB7.Signal=USART1_RX
PC13-TAMPER-RTC.Signal=GPIO_Output

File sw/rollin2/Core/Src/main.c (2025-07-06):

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
/* Includes ------------------------------------------------------------------*/
#include "main.h"
#include "i2c.h"
#include "tim.h"
#include "usart.h"
#include "gpio.h"

/* USER CODE BEGIN Includes */
#include "project.h"
#include "uart.h"
#include "str_buf.h"
#include "bldc_motor.h"
#include "bldc_driver.h"
#include "angle_sensor.h"

/* USER CODE END Includes */


/* USER CODE BEGIN PV */
bldc_motor_t m1;
bldc_driver_t md1;
angle_sens_t as1;
uart_t u1;

#define MAIN_STR_BUF_SIZE (128)
char main_str_buf[MAIN_STR_BUF_SIZE];

/* USER CODE END PV */

void SystemClock_Config(void);
/* USER CODE BEGIN 0 */
void waitabit(uint32_t x) {
	while(x) x--;
}
/*#include "calcs.h"
void test_calcs(void) {
  volatile float res;
  res = calcs_sinf_from_lut(0); // 0
  res = calcs_sinf_from_lut(45); // 0.707
  res = calcs_sinf_from_lut(60); // 0.866
  res = calcs_sinf_from_lut(90); // 0.1
  res = calcs_sinf_from_lut(135); // 0.707
  res = calcs_sinf_from_lut(180); // 1.22E-16
  res = calcs_sinf_from_lut(359); // -0.017
  res = calcs_sinf_from_lut(270); // -1
  return;
}*/
/* USER CODE END 0 */

/**
  * @brief  The application entry point.
  * @retval int
  */
int main(void)
{

  /* USER CODE BEGIN 1 */
	uint32_t now, last_tick, waitcnt;
	float dt, sum_dt;//, ang_deg_vel, prev_angle_deg, delta;
  /* USER CODE END 1 */

  /* MCU Configuration--------------------------------------------------------*/

  /* Reset of all peripherals, Initializes the Flash interface and the Systick. */
  HAL_Init();

  /* Configure the system clock */
  SystemClock_Config();

  /* Initialize all configured peripherals */
  MX_GPIO_Init();
  MX_I2C1_Init();
  MX_I2C2_Init();
  MX_TIM1_Init();
  MX_TIM2_Init();
  MX_TIM3_Init();
  MX_USART1_UART_Init();
  /* USER CODE BEGIN 2 */

  uart_init(&u1, USART1);

  angle_sensor_init(&as1, &hi2c1);

  bldc_driver_init(&md1, TIM1);
  bldc_driver_set_enable_pin(&md1, MOT0_EN_GPIO_Port, MOT0_EN_Pin);

  bldc_motor_init(&m1, &md1, &as1);
  //bldc_motor_set_ctrl_type(&m1, BLDC_MOTOR_CTRL_TYPE_VELOCITY_OPENLOOP);
  bldc_motor_set_ctrl_type(&m1, BLDC_MOTOR_CTRL_TYPE_ANGLE_OPENLOOP);
  bldc_motor_set_motor_parameters(&m1, 7, 360, 0.4f);
  bldc_motor_set_pid(&m1, 1.0f, 1.0f, 0.0f);
  bldc_motor_set_voltage_limit(&m1, 1.0f);
  bldc_motor_set_speed_limit(&m1, 1.0f);
  bldc_motor_set_target_speed(&m1, 1.0f);
  bldc_motor_set_target_angle_deg(&m1, 90.0f);

  bldc_driver_enable(&md1);
  //bldc_driver_set_pwm(&md1, 100, 200, 300);

  bldc_motor_enable(&m1);
  m1.set.voltage_q = 0.125f;

  /* USER CODE END 2 */

  /* Infinite loop */
  /* USER CODE BEGIN WHILE */

  now = HAL_GetTick();
  last_tick = now;
  uart_send_string_blocking(&u1, "hello from the other side :-D\n");
  angle_sensor_get(&as1);
  str_buf_clear(main_str_buf, MAIN_STR_BUF_SIZE);
  str_buf_append_uint16(main_str_buf, MAIN_STR_BUF_SIZE, as1.raw_angle);
  str_buf_append_string(main_str_buf, MAIN_STR_BUF_SIZE, "\n");
  uart_send_string_blocking(&u1, main_str_buf);
  waitcnt = 1;//0000;
  sum_dt = 0;

  //test_calcs();

  while (1)
  {
	  //waitabit(500000);
	  waitabit(waitcnt);

	  now = HAL_GetTick();
	  dt = (float)(now - last_tick)/1000.0f; // in ms
	  last_tick = now;

	  bldc_motor_move(&m1, dt);
//#if 0
	  str_buf_clear(main_str_buf, MAIN_STR_BUF_SIZE);
	  str_buf_append_float(main_str_buf, MAIN_STR_BUF_SIZE, m1.current.angle_deg, 3);
	  str_buf_append_string(main_str_buf, MAIN_STR_BUF_SIZE, ",");
//	  str_buf_append_float(main_str_buf, MAIN_STR_BUF_SIZE, m1.current.angle_deg_s, 3);
//	  str_buf_append_string(main_str_buf, MAIN_STR_BUF_SIZE, ",");
//	  str_buf_append_uint16(main_str_buf, MAIN_STR_BUF_SIZE, as1.raw_angle);
//	  str_buf_append_string(main_str_buf, MAIN_STR_BUF_SIZE, ",");
	  //str_buf_append_float(main_str_buf, MAIN_STR_BUF_SIZE, ang_deg_vel, 5);*/

	  //str_buf_append_float(main_str_buf, MAIN_STR_BUF_SIZE, statangle, 5);
	  //str_buf_append_string(main_str_buf, MAIN_STR_BUF_SIZE, ",");

	  str_buf_append_float(main_str_buf, MAIN_STR_BUF_SIZE, dbg_uu, 5);
	  str_buf_append_string(main_str_buf, MAIN_STR_BUF_SIZE, ",");
	  str_buf_append_float(main_str_buf, MAIN_STR_BUF_SIZE, dbg_uv, 5);
	  str_buf_append_string(main_str_buf, MAIN_STR_BUF_SIZE, ",");
	  str_buf_append_float(main_str_buf, MAIN_STR_BUF_SIZE, dbg_uw, 5);
	  str_buf_append_string(main_str_buf, MAIN_STR_BUF_SIZE, ",");

	  str_buf_append_uint16(main_str_buf, MAIN_STR_BUF_SIZE, statangle_u);
	  str_buf_append_string(main_str_buf, MAIN_STR_BUF_SIZE, ",");
	  str_buf_append_uint16(main_str_buf, MAIN_STR_BUF_SIZE, statangle_v);
	  str_buf_append_string(main_str_buf, MAIN_STR_BUF_SIZE, ",");
	  str_buf_append_uint16(main_str_buf, MAIN_STR_BUF_SIZE, statangle_w);
	  str_buf_append_string(main_str_buf, MAIN_STR_BUF_SIZE, ",");
	  str_buf_append_uint16(main_str_buf, MAIN_STR_BUF_SIZE, statangle_inc);

	  str_buf_append_string(main_str_buf, MAIN_STR_BUF_SIZE, "\n");
	  uart_send_string_blocking(&u1, main_str_buf);
//#endif

	  sum_dt += dt;
	  if(sum_dt > 2.0f) {
		  sum_dt = 0.0f;
		  m1.calc.shaft_angle_deg = 0;
		  m1.calc.shaft_angle_deg_old = 0;
		  bldc_motor_set_target_angle_deg(&m1, 150.0f);
		  bldc_motor_enable(&m1);
	  }
    /* USER CODE END WHILE */

    /* USER CODE BEGIN 3 */
  }
  /* USER CODE END 3 */
}

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


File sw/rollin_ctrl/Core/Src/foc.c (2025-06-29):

/**
 * Martin Egli
 * 2025-05-14
 * 
 * drive a BLDC motor using FOC
 * 
 * FOC: Field Oriented Control
 *   see: https://en.wikipedia.org/wiki/Vector_control_(motor)
 *        https://www.pmdcorp.com/resources/type/articles/get/field-oriented-control-foc-a-deep-dive-article
 *        and many more
 * this module is mcu dependend, supported: STM32F103
 */

// - includes ------------------------------------------------------------------
#include "foc.h"
#include "math.h"
#include "main.h"
#include <stdbool.h>

// - defines -------------------------------------------------------------------
#define FOC_BLDC_MOTOR1_TIMER (TIM1)
#define FOC_BLDC_MOTOR2_TIMER (TIM2)
// specify the bldc motors
#define FOC_BLDC_MOTOR_NB_COILS (3) // 3 coils 120° appart
// phase u, v, w
#define FOC_BLDC_MOTOR_NB_POLES (12)
#define FOC_BLDC_MOTOR_NB_MAGNETS (14)

// timer resolution 16 bits
#define FOC_PWM_TIMER_FREQ (8000000UL)
//#define FOC_PWM_MAX (65535UL)
#define FOC_PWM_MAX (799UL)
#define FOC_SIN_LUT_NB_VALUES (16UL)
#define FOC_SIN_LUT_SIZE (FOC_BLDC_MOTOR_NB_COILS*FOC_SIN_LUT_NB_VALUES)
#define FOC_SIN_LUT_MAX_INDEX (FOC_SIN_LUT_SIZE - 1)
#define FOC_SIN_LUT_U_START (0 * FOC_SIN_LUT_NB_VALUES)
#define FOC_SIN_LUT_V_START (1 * FOC_SIN_LUT_NB_VALUES)
#define FOC_SIN_LUT_W_START (2 * FOC_SIN_LUT_NB_VALUES)
#define FOC_SIN_OFFSET ((FOC_PWM_MAX+1)/2) // 1/2 of max
#define FOC_SIN_AMPLITUDE ((FOC_PWM_MAX/2)/2) // this determines the current through the coils

#define FOC_NB_STEPS_PER_FULL_ROTATION (FOC_SIN_LUT_SIZE * FOC_BLDC_MOTOR_NB_POLES / FOC_BLDC_MOTOR_NB_COILS)

#define FOC_MOTOR_MAX_SPEED (1000) // in 0.01 rev/s, -> 10 rev/s = max
#define FOC_MOTOR_DIR_FOREWARD (true)
#define FOC_MOTOR_DIR_BACKWARD (false)
#define FOC_SPEED_TIM (TIM3)
#define FOC_SPEED_TIM_FREQ (8000000UL/50)

// - private variables ---------------------------------------------------------
// testing NO static
static uint16_t sin_lut[FOC_SIN_LUT_SIZE];
static foc_t motors[FOC_NB_BLDC_MOTORS];

// - private functions ---------------------------------------------------------
// increment i+1 so it keeps between 0 ... MAX, else wrap around
static inline uint16_t inc_lut_index(uint16_t i) {
	if(i == FOC_SIN_LUT_MAX_INDEX) {
		return 0;
	}
	return i+1;
}

// increment i-1 so it keeps between 0 ... MAX, else wrap around
static inline uint16_t dec_lut_index(uint16_t i) {
	if(i == 0) {
		return FOC_SIN_LUT_MAX_INDEX;
	}
	return i-1;
}

// define if increment is foreward and decrement is backward or vice versa
#define NEXT_INDEX_FOREWARD(i) inc_lut_index(i)
#define NEXT_INDEX_BACKWARD(i) dec_lut_index(i)

#define IS_MOTOR_INDEX_VALID(mi) (mi < FOC_NB_BLDC_MOTORS)

// - public functions ----------------------------------------------------------
uint16_t foc_init(void) {
	uint16_t n;
	double x, w, wstep;

	LL_GPIO_SetOutputPin(GPIOC, LL_GPIO_PIN_13);
	// fill in sine wave lookup table
	w = 0.0;
	wstep = (2*M_PI)/FOC_SIN_LUT_SIZE;
	sin_lut[0] = FOC_SIN_OFFSET; // 1st value is already given: sin(0) + offset = offset
	for(n = 1; n < FOC_SIN_LUT_SIZE; n++) {
		w += wstep;
		x = (double)FOC_SIN_AMPLITUDE * sin(w) + (double)FOC_SIN_OFFSET;
		sin_lut[n] = (uint16_t)x;
	}
	// sin lut generation tested: 2025-05-14, Martin Egli: OK
	LL_GPIO_ResetOutputPin(GPIOC, LL_GPIO_PIN_13);
	
	// init motor 1
	motors[FOC_MOTOR1].TIM = FOC_BLDC_MOTOR1_TIMER;
	motors[FOC_MOTOR1].sin.u = FOC_SIN_LUT_U_START;
	motors[FOC_MOTOR1].sin.v = FOC_SIN_LUT_V_START;
	motors[FOC_MOTOR1].sin.w = FOC_SIN_LUT_W_START;
	motors[FOC_MOTOR1].speed_ctrl.tim_channel = LL_TIM_CHANNEL_CH1;
	motors[FOC_MOTOR1].x = 0;

	// init motor 2
	motors[FOC_MOTOR2].TIM = FOC_BLDC_MOTOR2_TIMER;
	motors[FOC_MOTOR2].sin.u = FOC_SIN_LUT_U_START;
	motors[FOC_MOTOR2].sin.v = FOC_SIN_LUT_V_START;
	motors[FOC_MOTOR2].sin.w = FOC_SIN_LUT_W_START;
	motors[FOC_MOTOR2].speed_ctrl.tim_channel = LL_TIM_CHANNEL_CH2;
	motors[FOC_MOTOR2].x = 0;

	return FOC_NB_BLDC_MOTORS;
}

void foc_start(void) {
	uint32_t cnt;
	LL_TIM_OC_SetCompareCH1(motors[FOC_MOTOR1].TIM, (uint32_t)sin_lut[motors[FOC_MOTOR1].sin.u]);
	LL_TIM_OC_SetCompareCH2(motors[FOC_MOTOR1].TIM, (uint32_t)sin_lut[motors[FOC_MOTOR1].sin.v]);
	LL_TIM_OC_SetCompareCH3(motors[FOC_MOTOR1].TIM, (uint32_t)sin_lut[motors[FOC_MOTOR1].sin.w]);
	LL_TIM_EnableAllOutputs(motors[FOC_MOTOR1].TIM);
	LL_TIM_CC_EnableChannel(motors[FOC_MOTOR1].TIM, LL_TIM_CHANNEL_CH1|LL_TIM_CHANNEL_CH2|LL_TIM_CHANNEL_CH3);
	LL_TIM_EnableCounter(motors[FOC_MOTOR1].TIM);

	motors[FOC_MOTOR1].speed_ctrl.tim_ccr = 0; // 10 rps

	LL_TIM_DisableIT_CC1(TIM3);
	cnt = LL_TIM_GetCounter(TIM3);
	LL_TIM_OC_SetCompareCH1(TIM3, cnt + motors[FOC_MOTOR1].speed_ctrl.tim_ccr);
	LL_TIM_ClearFlag_CC1(TIM3);
	LL_TIM_EnableIT_CC1(TIM3);
	LL_TIM_EnableCounter(TIM3);
	/*
	uint16_t tim_pwm = 0;
		HAL_TIM_Base_Start(&htim1);
		__HAL_TIM_SET_COMPARE(&htim1, TIM_CHANNEL_1, tim_pwm);
		HAL_TIM_PWM_Start(&htim1, TIM_CHANNEL_1);*/

	cnt = LL_TIM_GetCounter(TIM3);
	LL_TIM_OC_SetCompareCH4(TIM3, cnt + 10000);
	LL_TIM_ClearFlag_CC4(TIM3);
	LL_TIM_EnableIT_CC4(TIM3);

	return;
}
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

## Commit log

2022-09-09 added stand to test mpu9250
    [hold.scad, mpu9250angles.ods]
2022-09-09 added 1st testing routines to get familiar with mpu9250 all included in main.c, so project can be regenerated from test1.ioc using STM32CubeIDE
2022-09-10 mpu9250: more testing: found a complementary filter to get a reasonable angle from acc + gyro
    [mpu9250angles.ods]
2022-09-14 started with r1 (1st version of cad) but I cannot continue, parts have not arrived yet
    [electronics_parts.scad, hold.scad, mechanics_parts.scad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]
2022-09-16 copied from project pwmgen
2022-09-16 i2c routines
2022-09-17 1st bldc test: woohoo some movement, but no rotation :-(
    [Fpwm.ods]
2022-09-17 2nd attempt: this motor runs, actually quite fast
    using lookuptable sine[96], update every 8 timer1 interrupts = 144us ->
    turns at approx. 11 revolutions / s
    [Fpwm.ods]
2022-09-18 teststand created to mount motor + mpu6500
    [Fpwm.ods, motor_holderv1.0.3mf, motor_holderv1.0.stl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]
2022-09-18 mpu6500 i2c sucessful communication
2022-09-22 pid started
2022-09-24 r1: motor speed in motor.c
2022-09-24 start r01 using FlyCat 2204 Gimbal BLDC
    [electronics_parts.scad, mechanics_parts.scad, r_01.scad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]
2022-09-26 added nunchuck to rollin r1
    [electronics_parts.scad, r_01.scad]
2022-09-27 Makefile added reset to start bootloader and do nothing
    [main.c, motor.c]
2022-09-27 added scale to pwm (to scale torque) but do not use
2022-09-28 use motor to generate accurate timeout from TIMER0_OVF
2022-09-28 started PID tuneing
2022-09-28 change periode from 256 (62500 Hz) to 16 (1 MHz), so current does not go into saturation
    [Fpwm.ods]
2022-10-05 torque measurement of flycat 2204 motors: WAY TOO WEAK for this application
    I cannot proceed this way, I have to use more powerfull motors!
    [Fpwm.ods]
2022-10-05 kicad started L6230 driver board
    [l6230driver.kicad_pcb, l6230driver.sch]
2022-10-05 started pcb
    [l6230driver.kicad_pcb, l6230driver.sch]
2022-10-08 schematics + placing
    [l6230driver.kicad_pcb, l6230driver.kicad_sch]
2022-10-09 added HSOP-36 footprint to own pritty-lib, placing, routing
    [l6230driver.kicad_pcb, l6230driver.kicad_sch]
2022-10-09 100% routed
    [l6230driver.kicad_pcb, l6230driver.kicad_sch]
2022-10-11 export to order, added zip with gerber + drill
    [l6230driver.kicad_pcb]
2022-10-14 r02 started using 5010 gimbal bldc
    [electronics_parts.scad, mechanics_parts.scad, parts.scad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]
2022-10-14 printing r02 test stand and arm
    [mechanics_parts.scad, r02.scad, r02_lego_wheel_holder_v1.1.3mf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]
2022-10-16 added motor holder v1.0, including as5600 pcb
    [electronics_parts.scad, mechanics_parts.scad, r02.scad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]
2022-10-21 export brd + schematics
    [electronics_parts.scad, mechanics_parts.scad, r02.scad]
2022-10-31 added as5600 angle sensor
2022-11-09 upgraded to CubeIde 1.10, I2C LL, reading as5600 angles work
2024-08-30 started r03 from r02
    added m3_cut and m3_nut_bolt_cut
    [electronics_parts.scad, mechanics_parts.scad, parts.scad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]
2024-08-31 rav a of parts _1, _2, _3
    [electronics_parts.scad, r03.scad, screws.scad]
2024-08-31 rev b for parts _1, _2, _3
    [electronics_parts.scad, r03.scad, screws.scad]
2024-09-01 _1b minor adjustments, angles and nut dia
    [r03.scad, screws.scad]
2024-09-10 new mpuholder stand
    [hold.scad, mpu9250angles.ods]
2024-09-10 removed as5600 and therefore i2c
    also use str_buf functions from mmlib
2024-09-10 changed peripherials
    removed i2c1, usb
    added usart1, adc1 in8, in9
2024-09-11 sending data on uart: works
2025-05-14 rollin_ctrl use TIM3 to ctrl speed
    [Fpwm.ods]
2025-06-29 r04 started
    [Fpwm.ods, electronics_parts.scad, mechanics_parts.scad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]
2025-06-29 r04test_v1.1 added
    [rtest04.scad]
2025-07-02 changed i2c from LL to HAL, now reading as5600 is working
2025-07-06 rollin2 tested "bldc_motor_velocity_openloop()": OK, tested up to 7 rot/s

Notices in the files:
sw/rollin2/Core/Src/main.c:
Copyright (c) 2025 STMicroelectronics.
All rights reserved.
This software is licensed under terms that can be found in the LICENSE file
